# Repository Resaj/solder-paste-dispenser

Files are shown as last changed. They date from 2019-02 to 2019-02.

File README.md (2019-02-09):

# Solder paste dispenser

This project is based on the Geir Andersen's solder paste dispenser. His documentation can be found here:
- [Project forum](https://www.robotshop.com/community/forum/t/solder-paste-dispenser/31738)
- [3D parts](https://www.thingiverse.com/thing:384680) 

The electronic and programming parts are based on [this tutorial](https://42bots.com/tutorials/28byj-48-stepper-motor-with-uln2003-driver-and-arduino-uno/).

The version of my dispenser is very similar, but requires mounting an electronic prototipe and can be supplied by USB.

<p align="center">
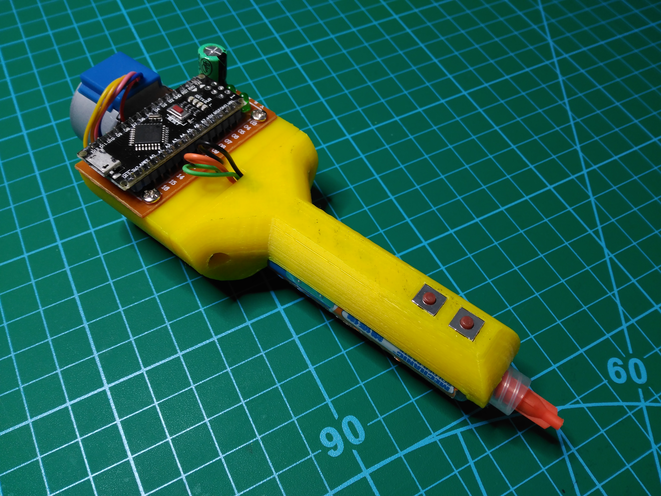
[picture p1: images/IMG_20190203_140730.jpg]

</p>

<p align="center">
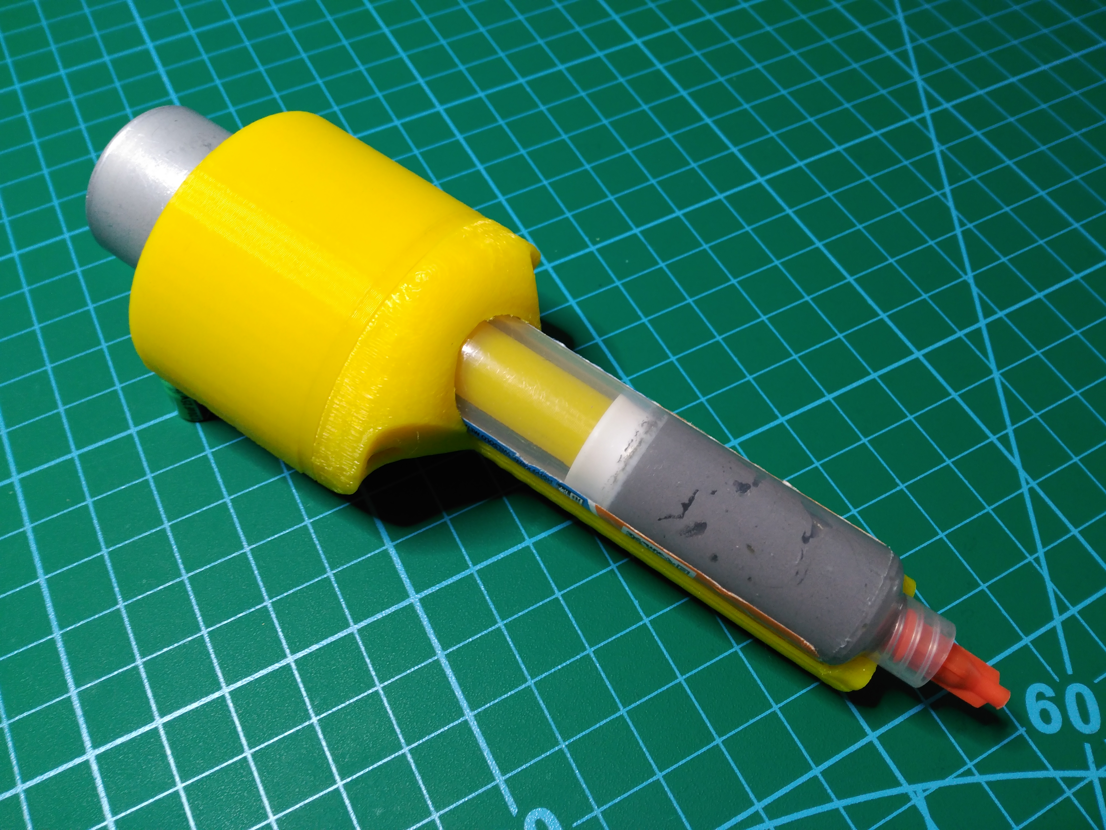
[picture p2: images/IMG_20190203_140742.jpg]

</p>

Here are the components of the project:
- 3D parts, who's files can be founded in this repository
- Solder paste syringe
- Syringe needle
- 28BYJ-48 5V stepper motor
- 5 to 5mm aluminum shaft coupler
- Threaded rod M5x60mm
- 2x carbon fiber rod 45x3mm
- Nut M5
- 2x M3x12mm screw
- 4x M3x6mm screw
- 6x M3 nut insert with 4mm external diameter
- Prototyping PCB
- Arduino with USB connector
- ULN2003 driver
- 2x pushbutton
- 2x led
- 2x 220 ohmios resistor
- Big capacitor for supply filtering
- Some wires

<p align="center">
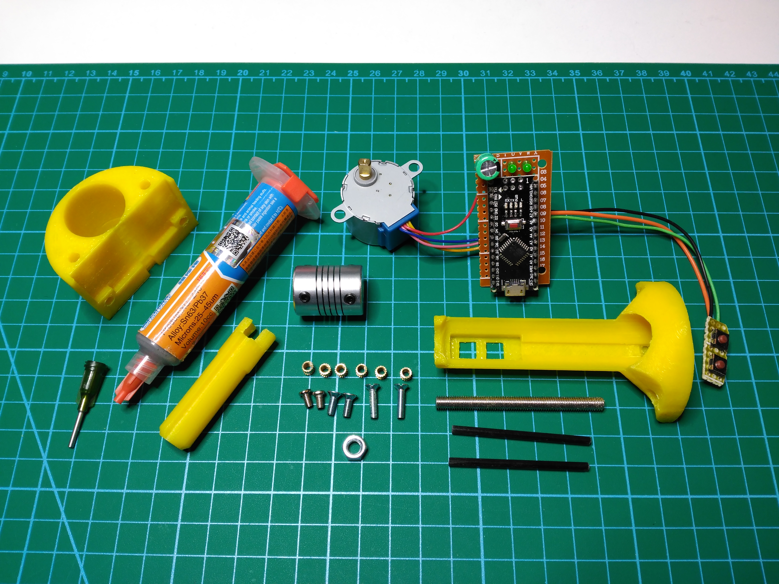
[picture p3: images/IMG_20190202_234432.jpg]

</p>

Please, pay attention when mounting the electronic prototype. The ULN2003 schema is the same than the mentioned tutorial, but used different pins of Arduino. That's the pin distribution:
- D2: led 2
- D3: led 1
- D4: forward pushbutton
- D5: backward pushbutton
- D6: ULN2003 to blue wire of motor
- D7: ULN2003 to pink wire of motor
- D8: ULN2003 to orange wire of motor
- D9: ULN2003 to yellow wire of motor

Function modes:
- One specific pushbutton (the front one) for pushing the paste
- Another button (the rear one) for change forward speed (short pulse; 4 different forward speeds, signaled with two leds on binary) and retract the piston (long pulse)

## Author

[Rubén Espino San José](https://github.com/Resaj)

## Licencia

<p align="center">



</p>

Todos estos productos están liberados mediante [Creative Commons Attribution-ShareAlike 4.0 International License](http://creativecommons.org/licenses/by-sa/4.0/).  

_All these products are released under [Creative Commons Attribution-ShareAlike 4.0 International License](http://creativecommons.org/licenses/by-sa/4.0/)._

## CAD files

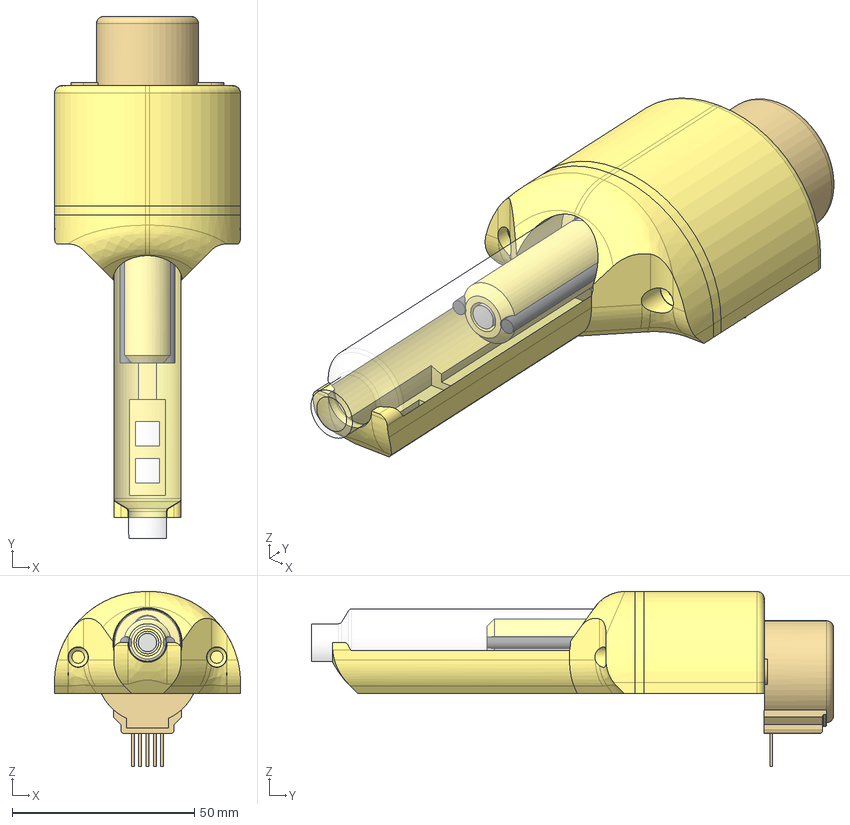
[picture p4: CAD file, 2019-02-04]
3D files/solder_paste_dispenser.FCStd
51.0 x 143.2 x 48.0 mm
Núcleo
28BYJ-48
ACOPLAMENTO_6_35X8
Guía_1
Guía_2
Varilla roscada
Tuerca
Émbolo
Jeringa
Carcasa
Adaptador

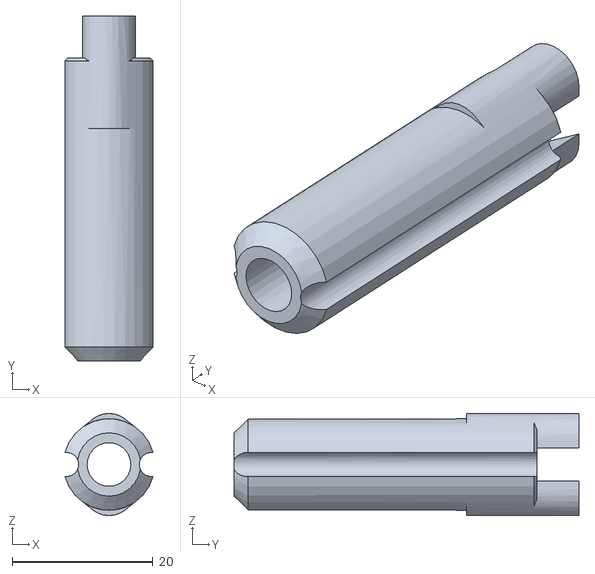
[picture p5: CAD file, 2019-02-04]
3D files/Émbolo.stl
12.6 x 49.0 x 14.5

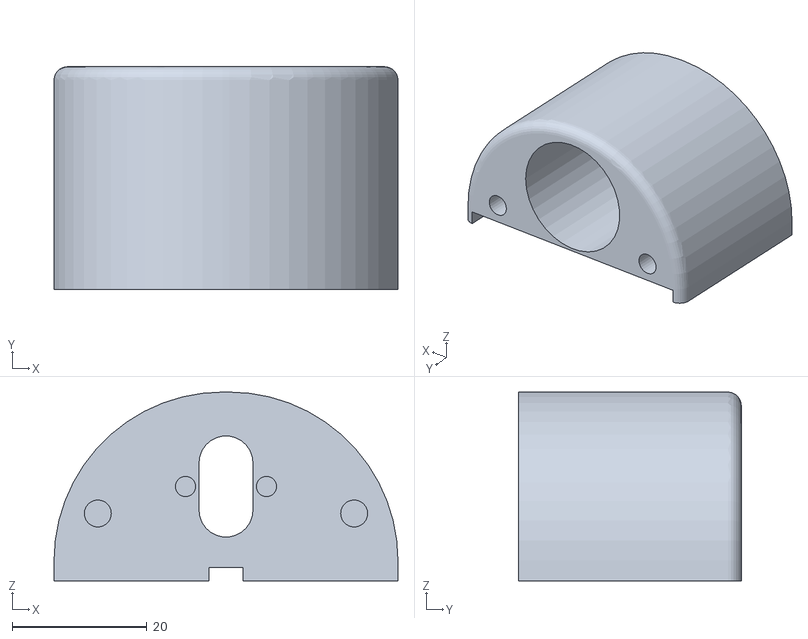
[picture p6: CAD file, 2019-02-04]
3D files/Núcleo.stl
51.0 x 33.0 x 28.0

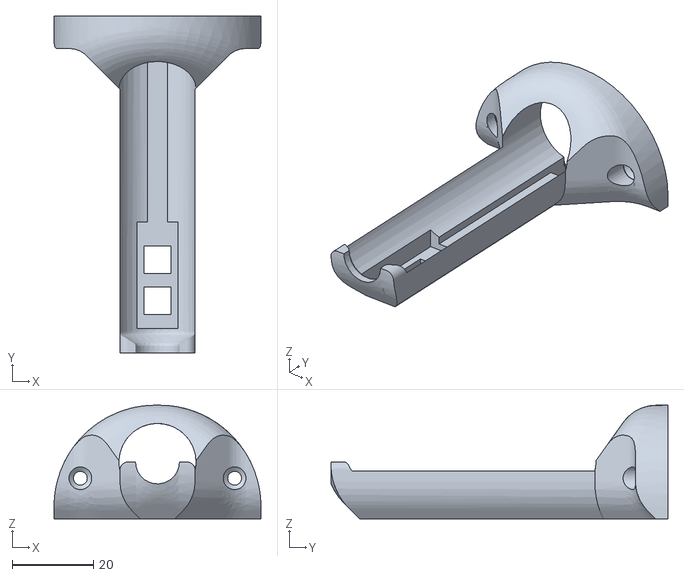
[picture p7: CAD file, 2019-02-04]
3D files/Carcasa.stl
51.0 x 83.0 x 28.0

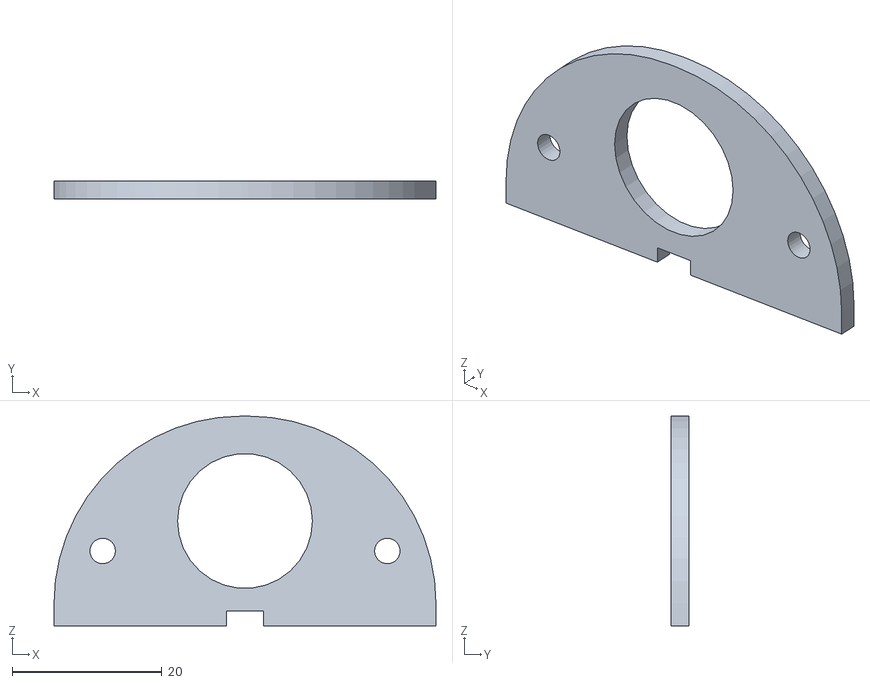
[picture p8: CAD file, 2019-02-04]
3D files/Adaptador.stl
51.0 x 2.40 x 28.0

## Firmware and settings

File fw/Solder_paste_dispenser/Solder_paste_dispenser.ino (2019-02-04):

#include <AccelStepper.h>
#define HALFSTEP 8

const int button_fw = 4;
const int button_bw = 5;
const int led_1 = 3;
const int led_2 = 2;

int speed_multiplier = 1; // 1 to 4

#define motorPin1  8     // IN1 on the ULN2003 driver 1
#define motorPin2  9     // IN2 on the ULN2003 driver 1
#define motorPin3  7     // IN3 on the ULN2003 driver 1
#define motorPin4  6     // IN4 on the ULN2003 driver 1

// Initialize with pin sequence IN1-IN3-IN2-IN4 for using the AccelStepper with 28BYJ-48
AccelStepper stepper(HALFSTEP, motorPin1, motorPin3, motorPin2, motorPin4);

long bw_time = 0, t = 0;
bool change_speed = false;

//////////////////////////////////////////////////////////////////////////////
void setup() {
  pinMode(button_fw, INPUT_PULLUP);
  pinMode(button_bw, INPUT_PULLUP);
  pinMode(led_1, OUTPUT);
  pinMode(led_2, OUTPUT);

  set_leds();

  stepper.setMaxSpeed(250.0);
  stepper.setAcceleration(10000.0);
  stepper.setSpeed(200.0);
}

//////////////////////////////////////////////////////////////////////////////
void loop() {
  t = millis();
  
  if (!digitalRead(button_bw)) {
    change_speed = true;
    if(t - bw_time > 400){
      stepper.setMaxSpeed(250.0*4);
      stepper.move(1000);
      change_speed = false;
    }
  }
  else
  {
    if(change_speed == true && t - bw_time > 50) {
      speed_multiplier++;
      if(speed_multiplier > 4)
        speed_multiplier = 1;

        set_leds();
    }
    
    bw_time = millis();
    if (!digitalRead(button_fw)) {
      stepper.setMaxSpeed(250.0*speed_multiplier);
      stepper.move(-1000);
    }
    else
      stepper.stop();
  }
      
  stepper.run();
}

void set_leds()
{
  switch(speed_multiplier)
  {
    case 1:
    digitalWrite(led_1, LOW);
    digitalWrite(led_2, LOW);
      break;
    case 2:
    digitalWrite(led_1, HIGH);
    digitalWrite(led_2, LOW);
      break;
    case 3:
    digitalWrite(led_1, LOW);
    digitalWrite(led_2, HIGH);
      break;
    default:
    digitalWrite(led_1, HIGH);
    digitalWrite(led_2, HIGH);
  }
}
